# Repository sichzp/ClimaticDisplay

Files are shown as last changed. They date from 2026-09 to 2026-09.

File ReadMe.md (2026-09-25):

# 🌡 ClimaticDisplay 2.66G

> **Климатический модуль с 4-цветным графическим экраном на электронных чернилах.**

**🇬🇧 [English (short)](#english-short)** · **🇷🇺 Русский — далее по документу**

---

## English (short)

**ClimaticDisplay 2.66G** is a self-powered wall-mounted climate monitor. An
**ESP32-C3** wakes up every 20 minutes from a **TPL5110** power timer, reads
temperature, humidity and atmospheric pressure from a **BME280**, keeps the time
and the previous readings in a **DS1307Z** RTC, redraws a 2.66" 4-color e-paper
screen and cuts its own power. It runs for months on two LiFePO4 cells.

Two firmwares share the same hardware: `ESP32-C3/` is a standalone Arduino build
with NTP time sync, while `ForESPHome/` is an ESPHome + Home Assistant build that
reports data to HA and refreshes the screen only when someone is at home.
Schematics, photos and full documentation are below, in Russian.

> **Note:** the device UI and all code comments are in **Russian**. Cyrillic glyphs
> are baked into the fonts (`ESP32-C3/fonts/*.h`, `ForESPHome/fonts/FreeSansBold.ttf`
> and the `glyphs:` lists in `ForESPHome/RoomClimatic.yaml`), so an English UI would
> require regenerating them. Translations are welcome.

---

## Описание прибора

Автономный настенный прибор на базе **ESP32-C3**: измеряет температуру, влажность и атмосферное давление, раз в 20 минут просыпается по таймеру, рисует свежие данные на e-paper дисплее и снова отключает питание. Работает от пары LiFePO4 аккумуляторов.

Существует в двух вариантах с одинаковым железом, но разным ПО:

| Вариант | Прошивка | Где стоит | Обмен данными |
|---|---|---|---|
| **Рабочий** | Arduino (`ESP32-C3/`) | На работе | Автономный, без сервера |
| **Домашний** | ESPHome (`ForESPHome/`) | Дома | Интеграция с Home Assistant |

---

## 🧭 Навигация по проекту

| Документ | Описание |
|---|---|
| [📄 Описание прибора](DOC/DeviceDescription.md) | Железо, характеристики, конструкция, распиновка |
| [⚙️ Алгоритм работы](DOC/Algorithm.md) | Пошаговый алгоритм обеих прошивок (Arduino и ESPHome) с блок-схемами |

---

## 📷 Фотографии

**Экран**

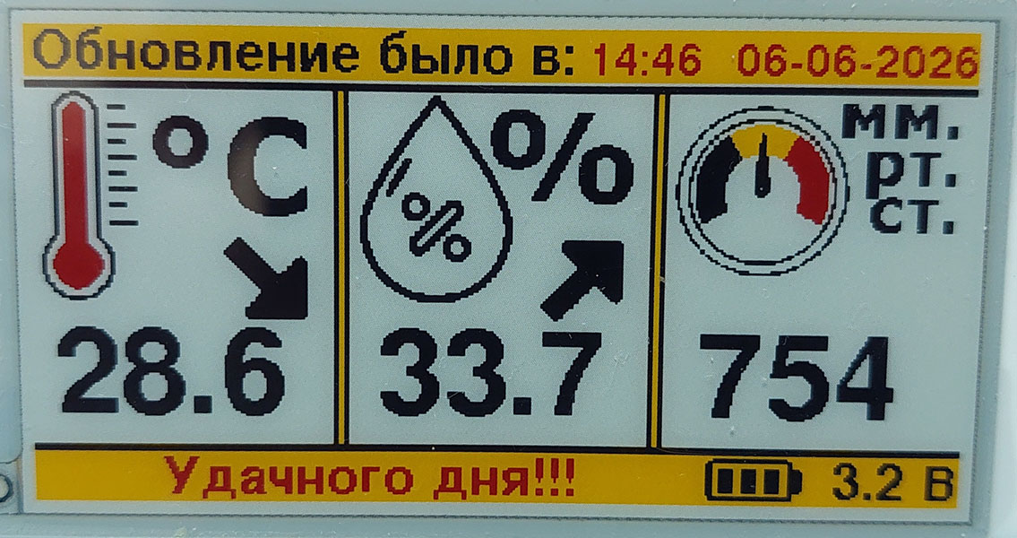
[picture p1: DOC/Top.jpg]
Дизайн экрана


**Вид сбоку**

| Справа | Слева |
|---|---|
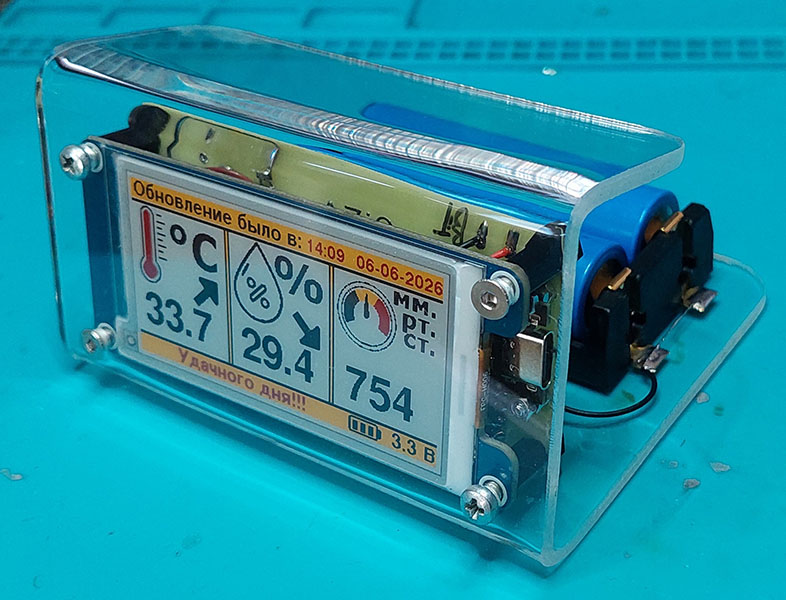
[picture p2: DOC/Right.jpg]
Вид справа
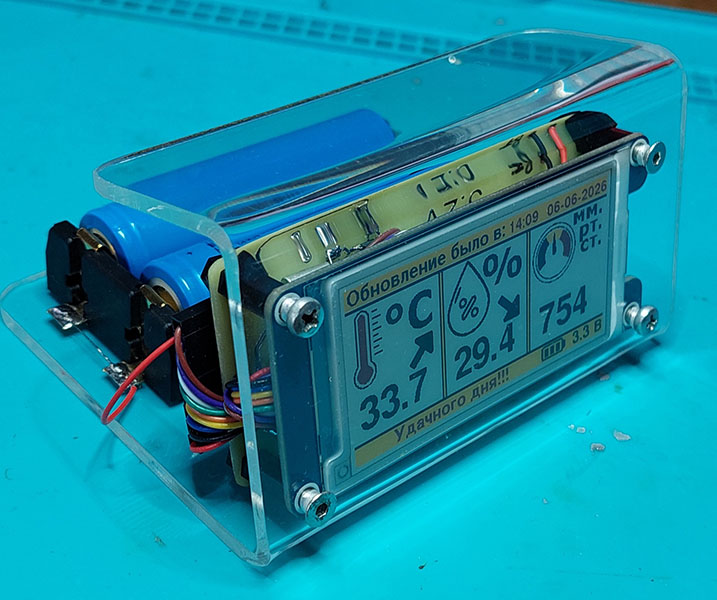
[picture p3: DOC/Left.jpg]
Вид слева
|  |  |

**Вид сзади**

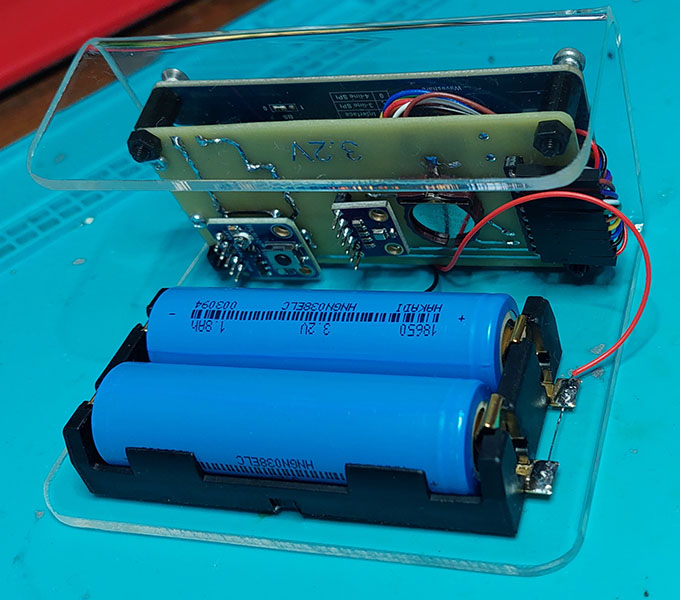
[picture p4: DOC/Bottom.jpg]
Вид сзади


**Корпус**

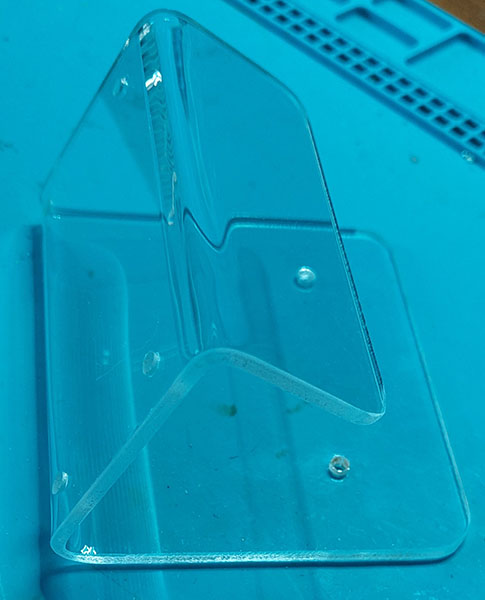
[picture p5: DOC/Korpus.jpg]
Корпус


**Схема и плата**

| Схема | Разведённая плата |
|---|---|
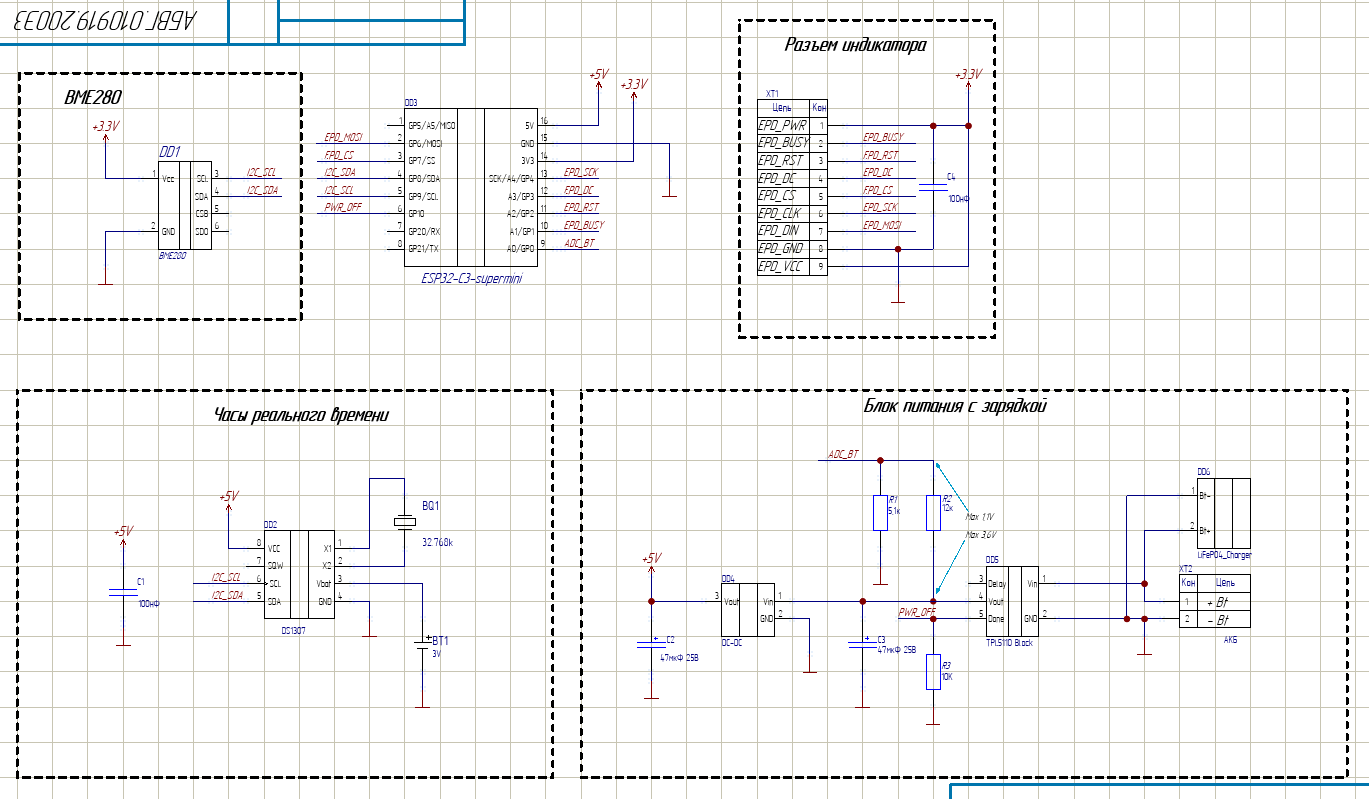
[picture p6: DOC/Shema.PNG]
Схема
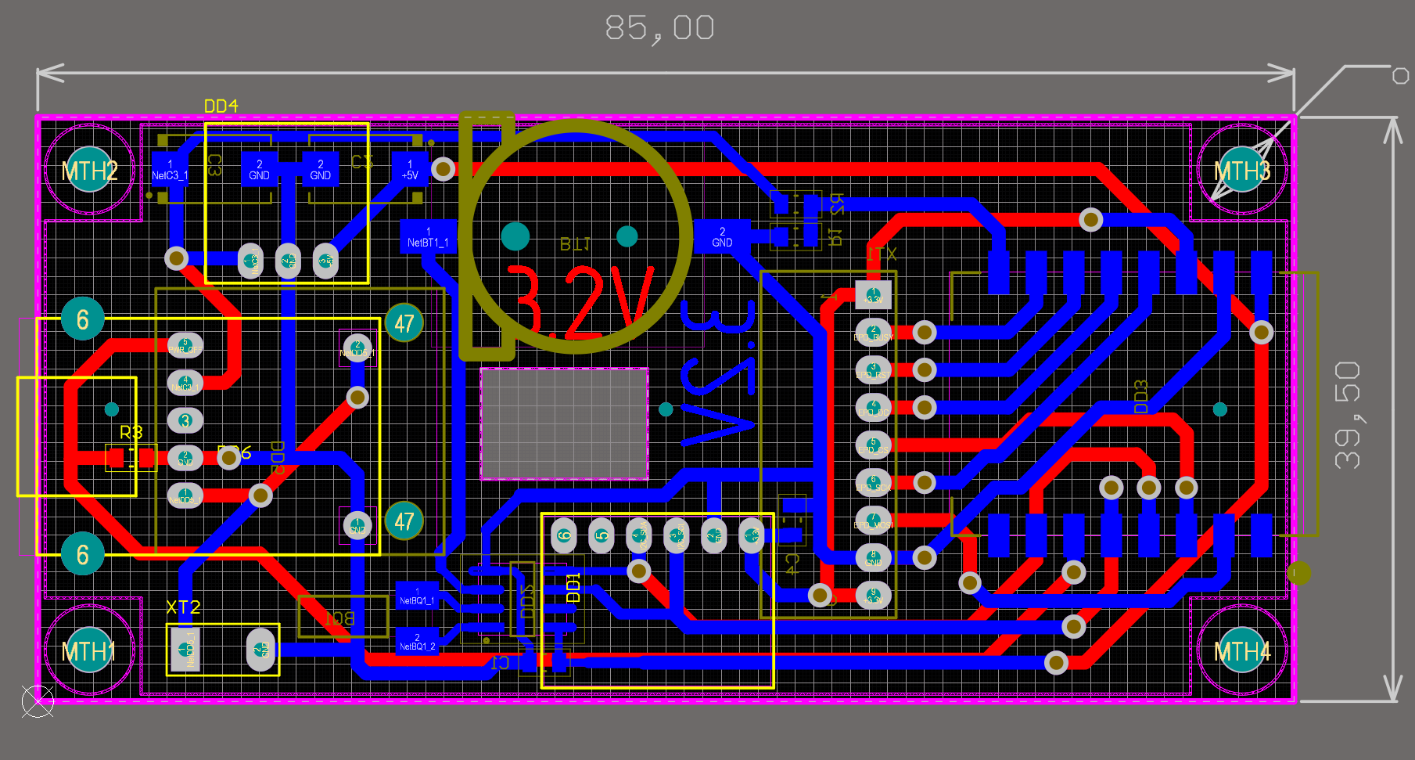
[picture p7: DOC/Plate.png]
Плата
|  |  |

| 3D модель, вид сверху | 3D модель, вид снизу |
|---|---|
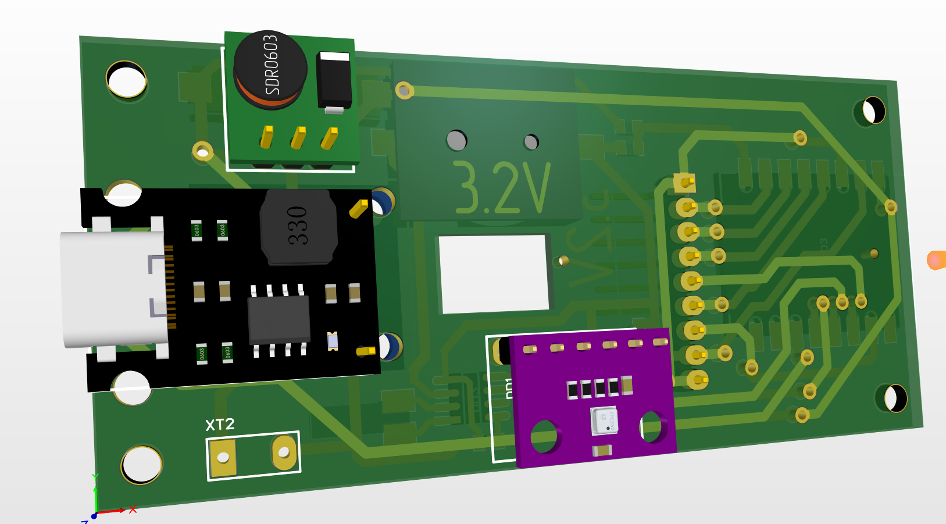
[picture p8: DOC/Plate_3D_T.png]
3D Модель платы Top
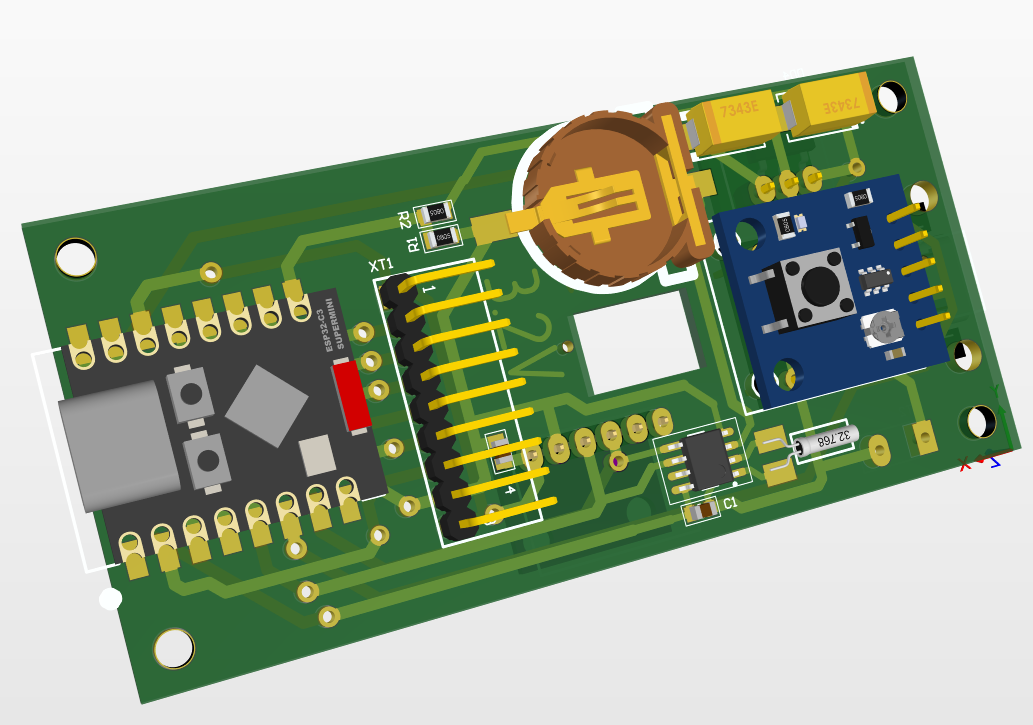
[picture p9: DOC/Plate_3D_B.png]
3D Модель платы Bottom
|  |  |

---

## 🖥 Что выводится на дисплей

1. 🌡 **Температура** + значок изменения (↑ / ↓);
2. 💧 **Влажность** + значок изменения;
3. 🌀 **Атмосферное давление** + значок изменения;
4. 🕒 **Время последнего обновления** (дата, время);
5. ⚠ **Ошибки** (если есть): соединение с сервером, общение с датчиками и часами;
6. 🔋 **Значок и напряжение заряда АКБ**.

---

## 🧰 Железо

| № | Компонент | Назначение |
|---|---|---|
| 1 | **ESP32-C3 Super Mini** | Микроконтроллерный модуль |
| 2 | **2.66" e-Paper Module (G), Waveshare** | 4-цветный графический дисплей 360×184 px |
| 3 | **BME280** | Датчик температуры, влажности и атмосферного давления |
| 4 | **DS1307Z** | Часы реального времени (кварц + батарейка) |
| 5 | **TPL5110** | Таймер включения прибора (каждые 20 минут) |
| 6 | **LiFePO4 ×2** | Аккумуляторы по 1,3 А·ч |
| 7 | **Модуль зарядки** | Зарядное устройство для АКБ |

---

## 💾 Прошивки

### 🧑‍💻 Arduino (рабочая версия) — `ESP32-C3/`

Полностью автономная прошивка: время синхронизируется по NTP через WiFi (по будням в 10:00), данные для стрелок ↑/↓ и биты ошибок хранятся в RAM DS1307Z. Ночью (23:00–04:00) прибор сразу выключается, экономя заряд АКБ.

### 🏠 ESPHome (домашняя версия) — `ForESPHome/`

Прошивка компилируется на сервере Home Assistant (файл `RoomClimatic.yaml`). Отличия от Arduino-версии:

- измеренные данные (температура, влажность, давление, напряжение АКБ, уровень WiFi) передаются в Home Assistant **при каждом включении, даже ночью**;
- время берётся с сервера Home Assistant, а при недоступности сервера — из DS1307Z; синхронизация DS1307Z — в обе стороны;
- экран не обновляется ночью (23:00–04:00) и когда **дома никого нет** (`input_boolean.people_at_home`) — экономия АКБ;
- режим **«обновление прошивки»** (`input_boolean.esphome_stay_awake`): прибор не выключается, пока флаг взведён (для OTA), максимум 1 час;
- стрелки ↑/↓ работают так же, как в Arduino-версии: прошлые показания хранятся в RAM DS1307Z;
- драйвер 4-цветного дисплея — внешний компонент `ForESPHome/components/gdey0266f51h` (портирован из GxEPD2), иконки конвертируются из Arduino-версии скриптом `ForESPHome/tools/convert_icons.py`.

> Для загрузки на сервер в папку `ForESPHome/` нужно положить файл шрифта `fonts/FreeSansBold.ttf` (GNU FreeFont — тот же шрифт, что используется в Arduino-версии), а также `secrets.yaml` с ключами `wifi_ssid` и `wifi_password` (на сервере они уже есть).

---

## 🔌 Порты модуля ESP32-C3 Super Mini

| Интерфейс | Назначение | Пин |
|---|---|---|
| **SPI** (дисплей) | SCK | D4 |
| | MOSI | D6 |
| | CS | D7 |
| | RST | D2 |
| | DC | D3 |
| | BUSY | D1 |
| | PWR | жёстко подтянут к VCC |
| **I2C** (BME280 + DS1307) | SDA | D8 |
| | SCL | D9 |
| **АЦП** (заряд АКБ) | A0 | D0 |
| **Питание** | PWR_OFF (TPL5110) | D10 |

---

## ⚙️ Алгоритм работы Arduino-версии (кратко)

Модуль **TPL5110** каждые 20 минут подаёт питание на схему. ESP32-C3 включается и выполняет:

1. Читает время и RAM из **DS1307Z**;
2. При необходимости синхронизирует время по **NTP** через WiFi (домашняя версия — ночью, рабочая — в 10:00 по будням, либо после прошлого сбоя);
3. Ночью (23:00–04:00) сразу выключается — экономия АКБ;
4. Настраивает и считывает данные из **BME280**;
5. Измеряет канал АЦП и пересчитывает его в напряжение **АКБ**;
6. Записывает данные в RAM **DS1307Z** — для показа ↑/↓ при следующем включении;
7. Формирует изображение и выводит его на **e-paper** дисплей;
8. Подаёт сигнал **TPL5110** на выключение питания.

Подробности и блок-схемы обеих версий (Arduino и ESPHome): [⚙️ Алгоритм работы](DOC/Algorithm.md)

---

## 🛠 ПО для разработки

| Что | Чем |
|---|---|
| Схема и плата | **Altium Designer 24.3.1** (компоненты из библиотеки автора — репозиторий `AltiumDesignerLibrary`) |
| Прошивка (Arduino) | **Arduino** для ESP32-C3, кодировка текстов **UTF-8** |
| Прошивка (ESPHome) | **ESPHome** (компилируется на сервере Home Assistant) |
| Корпус | **FreeCAD** |

> **ГОСТ шрифт:** для правильного отображения шрифта в Altium Designer необходимо установить в систему шрифт `Altium GOST Type A.ttf` из корня репозитория.

---

## 📚 Используемые библиотеки

| Библиотека | Для чего |
|---|---|
| [**GyverBME280**](https://github.com/GyverLibs/GyverBME280) | Датчик BME280 (Arduino-версия) |
| **DS1307** (`DS1307.h` / `DS1307.cpp`) | Собственная библиотека часов реального времени (Arduino-версия) |
| [**GxEPD2**](https://github.com/ZinggJM/GxEPD2) | Графический e-paper дисплей (Arduino-версия) |
| [**ESPHome**](https://esphome.io/) | Вся прошивка домашней версии (`ForESPHome/RoomClimatic.yaml`) |

---

## 📖 Документация

- [📄 Описание прибора](DOC/DeviceDescription.md)
- [⚙️ Алгоритм работы](DOC/Algorithm.md)
- [🙏 Благодарности и лицензии](CREDITS.md)

---

## 📜 Лицензия

Код, конфигурации, CAD-модели и документация — **MIT** (см. [LICENSE](LICENSE)): можно свободно
использовать, изменять и распространять, сохранив упоминание авторства.

Исключение — производные от GPL-компонентов: драйвер дисплея
`ForESPHome/components/gdey0266f51h/` (порт **GxEPD2**) распространяется под **GPL-3.0**,
шрифты — **GNU FreeFont** (GPL-3.0+ с Font Exception). Подробности и список сторонних
проектов: [🙏 Благодарности и лицензии](CREDITS.md).

---

👨‍💻 **Разработчик: Кабанов Алексей, 2026 г.**

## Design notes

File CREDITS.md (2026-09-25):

# 🙏 Благодарности и лицензии сторонних компонентов

> **Навигация:** [← На главную](ReadMe.md)

Проект не появился бы без чужих открытых наработок. Ниже — что и откуда взято,
чтобы было понятно, кому и за что спасибо.

---

## Сторонние проекты

| Проект | Автор | Лицензия | Где используется |
|---|---|---|---|
| [**GxEPD2**](https://github.com/ZinggJM/GxEPD2) | Jean-Marc Zingg (ZinggJM) | GPL-3.0 | Arduino-версия: вывод картинки на e-paper. Драйвер `gdey0266f51h` для ESPHome — **порт** класса `GxEPD2_266c_GDEY0266F51H` (последовательности инициализации и работа с 4-цветными панелями) |
| [**GyverBME280**](https://github.com/GyverLibs/GyverBME280) | AlexGyver (GyverLibs) | MIT | Arduino-версия: датчик BME280 |
| [**ESPHome**](https://esphome.io/) | ESPHome / Nabu Casa | GPL-3.0 | Домашняя версия: вся прошивка и внешние компоненты |
| [**GNU FreeFont**](https://www.gnu.org/software/freefont/) (FreeSans Bold) | GNU Project | GPL-3.0+ с Font Exception | Шрифты на экране: `ESP32-C3/fonts/`, `ForESPHome/fonts/FreeSansBold.ttf`. Растровые версии сделаны на [truetype2gfx](https://rop.nl/truetype2gfx/), иконки — в программе Img2Lcd |
| Демо-примеры Waveshare / Good Display для JD79667 | Waveshare / Good Display | — | Использованы как справка по регистрам панели GDEY0266F51H |
| [**Altium Designer**](https://www.altium.com/) | Altium | — | Схема и разводка платы (`Altium/`). Компоненты — из библиотеки автора (`AltiumDesignerLibrary`) |
| [**FreeCAD**](https://www.freecad.org/) | FreeCAD Community | LGPL-2.1 | 3D-модели платы и корпуса (`CAD/`) |
| [**LightBurn**](https://lightburnsoftware.com/) | LightBurn Software | — | Проект лазерной резки корпуса (`CAD/PlateLaser.lbrn2`) |

Даташиты на компоненты лежат в `DOC/`: [DS1307Z](DOC/ds1307.pdf), [TPL5110](DOC/tpl5110.pdf).

---

## Лицензия этого проекта

Всё, что написано автором (прошивка `ESP32-C3/`, конфигурация и компоненты
`ForESPHome/`, скрипты, CAD-модели, документация), распространяется по
лицензии **MIT** — см. [LICENSE](LICENSE). Коротко: можно использовать,
менять, продавать и встраивать куда угодно, главное — сохранить упоминание
авторства и не предъявлять претензий, если что-то сломалось.

**Исключение** — производные от GPL-компонентов:

- `ForESPHome/components/gdey0266f51h/` — производная работа от GxEPD2
  (GPL-3.0), поэтому распространяется под **GPL-3.0**
  (текст: <https://www.gnu.org/licenses/gpl-3.0.txt>). Если вы используете или
  распространяете этот компонент, действуют условия GPL-3.0;
- шрифты `ESP32-C3/fonts/*.h` и `ForESPHome/fonts/FreeSansBold.ttf` — GNU FreeFont
  под GPL-3.0+ с Font Exception: встраивание шрифта в изображение или документ
  не делает их производной работой, но при распространении самого файла шрифта
  действует GPL.

Отдельно: Arduino-версия прошивки собирается с библиотекой GxEPD2 (GPL-3.0),
поэтому **собранный бинарник** — уже под GPL-3.0, даже несмотря на MIT у
исходного скетча. Для домашнего хобби-проекта это никак не мешает.

---

## Навигация

[← На главную](ReadMe.md)

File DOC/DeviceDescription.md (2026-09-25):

# 📄 ClimaticDisplay 2.66G — описание прибора

> **Навигация:** [← На главную](../ReadMe.md) · [⚙️ Алгоритм работы](Algorithm.md)

---

## Назначение

Автономный настенный климатический модуль для отображения температуры, влажности и атмосферного давления. Прибор не работает постоянно: таймер **TPL5110** раз в 20 минут подаёт питание, **ESP32-C3** проводит измерение, обновляет картинку на экране и отключает питание. Благодаря e-paper дисплею картинка остаётся видимой без потребления энергии.

---

## Технические характеристики

| Параметр | Значение |
|---|---|
| Микроконтроллер | ESP32-C3 (RISC-V, WiFi) |
| Дисплей | 2.66" e-paper, 4 цвета: чёрный, белый, красный, жёлтый; 360×184 px |
| Датчик | BME280: температура, влажность, атмосферное давление |
| Часы | DS1307Z (I2C) с кварцем и резервной батарейкой |
| Питание | 2 × LiFePO4 1,3 А·ч (≈3,2 В) + модуль зарядки |
| Управление питанием | TPL5110 — включение каждые 20 минут; ночью (23:00–04:00) и при отсутствии людей дома экран не обновляется — экономия АКБ |
| Потребление | только в момент измерения и отрисовки (секунды) |

---

## Структурная схема

```mermaid
flowchart TD
    BME[BME280 датчик] -->|I2C| ESP[ESP32-C3]
    RTC[DS1307Z часы] -->|I2C| ESP
    AKB[АКБ LiFePO4] -->|делитель, АЦП A0| ESP
    TPL[TPL5110 таймер] -->|подаёт питание| ESP
    ESP -->|SPI| EPD[E-paper 2.66"]
    ESP -->|DONE, D10| TPL
```

---

## Описание узлов

### ESP32-C3 Super Mini
Микроконтроллерный модуль на базе ESP32-C3. Выполняет весь алгоритм: опрос датчиков, синхронизацию времени по NTP, отрисовку экрана и управление питанием.

### Дисплей 2.66" e-Paper (G), Waveshare
Четырёхцветный графический дисплей на электронных чернилах (GDEY0266F51H), 184×360 px (в проекте повёрнут на 90° — 360×184). Подключение по SPI. Картинка сохраняется без питания, поэтому используется полная перерисовка один раз за цикл. Работает через библиотеку **GxEPD2**.

### BME280
Датчик температуры, влажности и атмосферного давления. Подключён по I2C, работает в принудительном режиме (FORCED): по одному измерению за включение — так экономится энергия.

### DS1307Z
Микросхема часов реального времени (I2C) с кварцем и резервной батарейкой — время не сбрасывается при отключении основного питания. Помимо часов, имеет **56 байт RAM**: в них хранятся показания прошлого измерения и биты ошибок, чтобы при следующем включении нарисовать стрелки ↑/↓ и сохранить историю сбоев. Этот механизм используют обе прошивки (формат `AllData_t` совместим: переход между Arduino и ESPHome не ломает стрелки ↑/↓).

### TPL5110
Микромощный таймер, управляющий питанием всей схемы: каждые 20 минут замыкает питание. ESP32-C3 по окончании работы подаёт сигнал **DONE** (пин D10) — TPL5110 снимает питание до следующего цикла.

**Пример схемы включения TPL5110:**

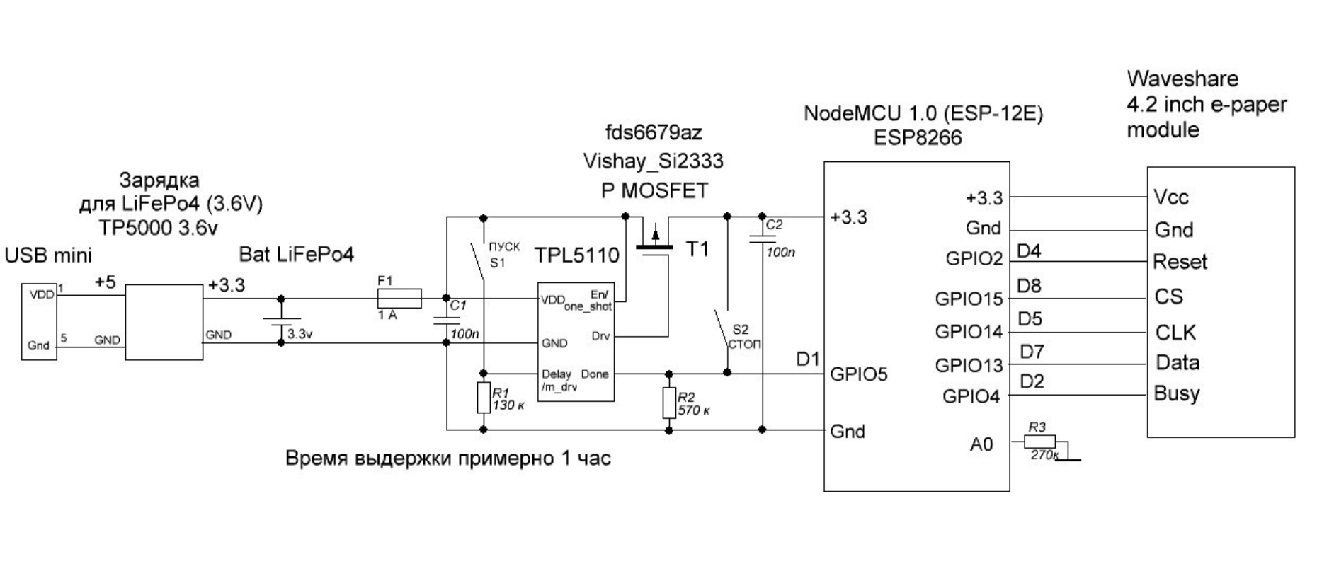
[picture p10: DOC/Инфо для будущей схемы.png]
Пример схемы включения TPL5110


Экономия АКБ реализована по-разному в двух прошивках:

- **Arduino-версия**: ночью (23:00–04:00) после чтения времени и синхронизации (при необходимости) прибор подаёт DONE сразу — измерения и обновление экрана пропускаются;
- **ESPHome-версия**: данные всегда измеряются и передаются на сервер, но экран не обновляется ночью (23:00–04:00) и когда дома никого нет (`input_boolean.people_at_home = off`); в режиме обновления прошивки (`input_boolean.esphome_stay_awake = on`) DONE не подаётся до снятия флага (максимум 1 час) — это позволяет выполнить OTA.

### Питание
Два аккумулятора **LiFePO4** по 1,3 А·ч (номинал ≈3,2 В) и модуль зарядного устройства. Уровень заряда контролируется через АЦП (пин A0). При разряде АКБ на экран выводится соответствующая ошибка.

---

## Распиновка ESP32-C3 Super Mini

| Интерфейс | Назначение | Пин |
|---|---|---|
| **SPI** (дисплей) | SCK | D4 |
| | MOSI | D6 |
| | CS | D7 |
| | RST | D2 |
| | DC | D3 |
| | BUSY | D1 |
| | PWR | жёстко подтянут к VCC |
| **I2C** (BME280 + DS1307) | SDA | D8 |
| | SCL | D9 |
| **АЦП** (заряд АКБ) | A0 | D0 |
| **Питание** | PWR_OFF (TPL5110) | D10 |

---

## Компоновка экрана

Экран 360×184 px состоит из трёх окон и двух колонтитулов:

| Зона | Координаты (x, y, ширина, высота) | Содержимое |
|---|---|---|
| Верхний колонтитул | (0, 0, 360, 20) — жёлтый | «Обновление было в: ЧЧ:ММ ДД-ММ-ГГГГ» |
| Разделитель | (0, 21, 360, 3) — чёрный | — |
| Окно температуры | иконка (1, 25, 112, 80) · стрелка (74, 80, 32, 32) · значение (8, 148) | градусник, ↑/↓, значение °C |
| Разделитель 1 | (116, 24, 2, 137) чёрный · (118, 24, 3, 137) жёлтый · (120, 24, 2, 137) чёрный | — |
| Окно влажности | иконка (123, 25, 112, 80) · стрелка (196, 80, 32, 32) · значение (132, 148) | капля, ↑/↓, значение % |
| Разделитель 2 | (238, 24, 2, 137) чёрный · (240, 24, 3, 137) жёлтый · (242, 24, 2, 137) чёрный | — |
| Окно давления | иконка (245, 25, 112, 80) · стрелка (317, 80, 32, 32) · значение (257, 148) | барометр, ↑/↓, значение мм рт. ст. |
| Нижний разделитель | (0, 161, 360, 3) — чёрный | — |
| Нижний колонтитул | (0, 164, 360, 20) — жёлтый | ошибки слева, значок АКБ (260, 165, 40, 18) и напряжение (310, 180) справа |

---

## Индикация ошибок

Ошибки хранятся в виде битовой маски (2 байта) в RAM DS1307Z и выводятся в нижнем колонтитуле экрана:

| Бит | Обозначение | На экране | Значение |
|---|---|---|---|
| 0 | DS1307Z | `\|TM\|` | МС часов реального времени не отвечает |
| 1 | BME280 | `\|BME\|` | Датчик BME280 не отвечает |
| 2 | Battery | `\|Bt\|` | АКБ разряжен |
| 3 | WiFi | `\|WF\|` | Нет подключения к WiFi |
| 4 | NTP | `\|NTP\|` | Нет ответа от сервера времени |
| 5 | TimeRST | `\|TM_Rst\|` | Время часовой МС было сброшено |
| 6–15 | — | — | Резерв |

Если ошибок нет — в нижнем колонтитуле выводится «Удачного дня!!!».

> В ESPHome-версии ошибки не хранятся в RAM, а формируются на лету по состоянию датчиков: `|TM|` — нет времени, `|BME|` — датчик не отвечает, `|Bt|` — АКБ < 2,5 В, `|WF|` — нет связи с сервером, `|OTA|` — режим ожидания прошивки. Подробнее: [⚙️ Алгоритм работы](Algorithm.md).

---

## Конструкция

- **Корпус** — модель в FreeCAD (`CAD/Корпус.FCStd`), печать/фрезеровка;
- **Плата** — разработана в Altium Designer (`Altium/`), смотри фото ниже.

| Фото | Описание |
|---|---|
| Схема | Принципиальная схема |
| Плата | Разведённая плата |
| 3D Top | 3D-модель платы, вид сверху |
| 3D Bottom | 3D-модель платы, вид снизу |
| Экран | Экран устройства |
| Корпус | Корпус |

---

## Навигация

[← На главную](../ReadMe.md) · [⚙️ Алгоритм работы](Algorithm.md)

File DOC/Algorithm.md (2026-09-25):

# ⚙️ ClimaticDisplay 2.66G — алгоритм работы

> **Навигация:** [← На главную](../ReadMe.md) · [📄 Описание прибора](DeviceDescription.md)

Документ описывает обе прошивки прибора:

- [Часть 1. Arduino-версия (рабочий прибор)](#часть-1-arduino-версия-рабочий-прибор)
- [Часть 2. ESPHome-версия (домашний прибор)](#часть-2-esphome-версия-домашний-прибор)

---

# Часть 1. Arduino-версия (рабочий прибор)

## Общая идея

Прибор не работает постоянно. Таймер **TPL5110** раз в 20 минут подаёт питание на схему, **ESP32-C3** просыпается, делает замер, обновляет экран и сам себя выключает. Поэтому весь код программы размещён в `setup()`, а `loop()` пуст.

Ночью (с 23:00 до 04:00) прибор экономит заряд АКБ: он синхронизирует время по NTP (если это нужно) и сразу выключается — без измерений и обновления экрана.

```mermaid
flowchart TD
    A[TPL5110 подаёт питание] --> B[Инициализация ESP32-C3]
    B --> C[Чтение времени из DS1307Z]
    C --> D[Чтение RAM DS1307Z]
    D --> E{Нужно обновить<br/>время по NTP?}
    E -- Да --> F[Подключение к WiFi]
    F --> G[Синхронизация по NTP]
    G --> H[Запись времени в DS1307Z]
    E -- Нет --> I{Ночь 23:00-04:00<br/>и часы в порядке?}
    H --> I
    I -- Да --> X[Сразу выключаемся<br/>без измерений]
    I -- Нет --> J[Чтение BME280]
    J --> K[Измерение АКБ]
    K --> L[Сохранение данных в RAM DS1307Z]
    L --> M[Отрисовка e-paper]
    M --> N[PWR_OFF — выключение питания]
```

---

## Пошаговый алгоритм

### Шаг 1. Чтение времени из DS1307Z

1. Проверка наличия МС на линии I2C (чтение регистра дня недели);
   - нет ответа → бит ошибки `DS1307Z`;
2. Чтение даты и времени (8 регистров, BCD);
3. Проверка актуальности: если год < 26 — часы были сброшены → бит `TimeRST`.

### Шаг 2. Чтение RAM DS1307Z

Читаются 8 байт RAM — прошлые показания (`AllDataOld`) для стрелок ↑/↓ и биты ошибок прошлого цикла.

### Шаг 3. Синхронизация времени по NTP

Условия обновления времени:

| Версия прошивки | Условие |
|---|---|
| Домашняя (`VER_FOR_HOME`) | 00:00–00:20 |
| Рабочая (по умолчанию) | 10:00–10:20 в будние дни |
| Любая | время было сброшено (`TimeRST`), или в прошлый раз не удалось подключиться к WiFi/NTP |

Порядок действий:

1. Подключение к WiFi (таймаут ~30 с) → при неудаче бит `WiFi`;
2. Запрос времени у NTP-сервера (таймаут ~30 с) → при неудаче бит `NTP`;
3. Перевод времени в BCD и запись в DS1307Z;
4. Отключение WiFi и переход модуля в `WIFI_OFF` — экономия энергии.

### Шаг 4. Ночной режим экономии АКБ

После синхронизации проверяется текущее время:

- если МС ответила, время актуально и сейчас **23:00–04:00** — прибор **сразу выключается**: измерения и обновление экрана пропускаются;
- если время было сброшено (`TimeRST`) или МС не ответила — не спим, а работаем дальше (покажем ошибку или данные).

Интервал настраивается макросами `NIGHT_START_HOUR` / `NIGHT_END_HOUR` (формат BCD).

### Шаг 5. Чтение датчика BME280

1. Датчик переводится в принудительный режим (`FORCED_MODE`) — одно измерение за включение, экономия энергии;
2. Если датчик не ответил — выставляется бит ошибки `BME280`;
3. Считываются температура и влажность (×10), давление пересчитывается в мм рт. ст. (×10).

### Шаг 6. Измерение напряжения АКБ

1. Читается канал АЦП (пин A0) через `analogReadMilliVolts()` — точнее, чем `analogRead()`;
2. Значение пересчитывается в напряжение АКБ (с учётом делителя);
3. Если напряжение ниже порога — бит ошибки `Battery`.

### Шаг 7. Сохранение данных в RAM DS1307Z

Текущие показания датчиков (8 байт структуры `AllData_t`) записываются в RAM микросхемы часов. При следующем включении они станут «старыми» и позволят нарисовать стрелки ↑/↓ изменения.

### Шаг 8. Отрисовка экрана

1. Инициализация GxEPD2, поворот на 90° (`setRotation(1)`), заливка белым;
2. Верхний колонтитул: жёлтая плашка со временем последнего обновления;
3. Три окна: температура (с градусником, окрашенным по диапазону), влажность, давление (иконка по диапазону);
4. Стрелки ↑/↓ — сравнение с прошлыми показаниями из RAM;
5. Нижний колонтитул: ошибки (или «Удачного дня!!!») + значок и напряжение АКБ;
6. `display()` — вывод картинки, `hibernate()` — перевод экрана в режим сна.

### Шаг 9. Выключение питания

Пин `PWR_OFF` (D10) переводится в высокий уровень — сигнал **DONE** для TPL5110, который снимает питание со всей схемы до следующего цикла.

---

## Отладочные макросы прошивки

| Макрос | Назначение |
|---|---|
| `DEBUG` | Вывод отладочной информации в Serial (115200) |
| `NO_BME280` | Отключить работу с BME280 |
| `NO_DS1307` | Отключить работу с DS1307 |
| `NO_GxEPD2` | Отключить работу с экраном |
| `VER_FOR_HOME` | Домашняя версия: обновление времени ночью |
| `POWER_AKB_32V` | Питание от LiFePO4 3,2 В (включено по умолчанию) |
| `POWER_AKB_42V` | Питание от LiPo 4,2 В |
| `NIGHT_START_HOUR` | Начало ночного режима: 23:00 (в формате BCD) |
| `NIGHT_END_HOUR` | Конец ночного режима: 04:00 (в формате BCD) |

---

# Часть 2. ESPHome-версия (домашний прибор)

> Конфигурация: `ForESPHome/RoomClimatic.yaml` (компилируется на сервере Home Assistant).

## Общая идея

Принцип тот же: TPL5110 включает прибор каждые 20 минут, ESP32-C3 загружается, выполняет сценарий `Execute_and_off` (запускается автоматически после загрузки) и подаёт сигнал DONE на выключение. Отличия от Arduino-версии:

- прибор всегда подключается к WiFi и Home Assistant, чтобы **передать данные датчиков** — в том числе ночью и когда дома никого нет;
- время приходит с сервера Home Assistant; при недоступности сервера используется время из DS1307Z (автономный режим);
- экран обновляется не каждое включение: ночью (23:00–04:00) и при отсутствии людей дома (`input_boolean.people_at_home = off`) отрисовка пропускается ради экономии АКБ;
- режим обновления прошивки (`input_boolean.esphome_stay_awake = on`) удерживает прибор включённым до OTA-обновления, но не более 1 часа.

```mermaid
flowchart TD
    A[TPL5110 подаёт питание] --> B[Загрузка ESPHome + подключение к WiFi]
    B --> C{Время валидно<br/>и сервер доступен?}
    C -- Нет --> W[Ожидание до 30 с]
    W --> C
    C --> D{Время валидно?}
    D -- Да --> E[ds1307.write_time<br/>сервер → DS1307Z]
    D -- Нет --> F[ds1307.read_time<br/>DS1307Z → прибор]
    E --> G[Измерение BME280, АЦП АКБ, WiFi]
    F --> G
    G --> H[Пауза 3 с — данные уходят на сервер]
    H --> I[Чтение старых данных из RAM DS1307Z]
    I --> J{Ночь 23:00-04:00<br/>или никого нет дома?}
    J -- Нет --> K[Отрисовка e-paper]
    J -- Да --> L[Экран пропускаем]
    K --> M[Сохранение данных в RAM DS1307Z]
    L --> M
    M --> N{esphome_stay_awake?}
    N -- Да --> O[Ждём снятия флага<br/>до 1 часа]
    O --> P[DONE — выключение питания]
    N -- Нет --> P
```

## Пошаговый алгоритм сценария `Execute_and_off`

### Шаг 1. Ожидание сервера и времени

После загрузки ждём 10 секунд (подключение к WiFi), затем сценарий проверяет условие «время валидно и сервер доступен» и ждёт его до 30 секунд:

- если сервер доступен — время синхронизируется с Home Assistant (платформа `homeassistant`, интервал 10 с — чтобы успеть за короткое включение);
- если сервер недоступен — продолжаем без него (автономный режим).

### Шаг 2. Синхронизация часов DS1307Z

- время валидно (есть сервер) → действие `ds1307.write_time` записывает время сервера в МС — часы остаются точными для будущих автономных включений;
- время невалидно (нет сервера) → действие `ds1307.read_time` берёт время из МС — прибор работает без сети.

### Шаг 3. Измерение датчиков

Действиями `component.update` принудительно измеряются BME280 (температура, влажность, давление → мм рт. ст.), напряжение АКБ (АЦП) и уровень WiFi. После 3-секундной паузы значения гарантированно переданы на сервер — **даже ночью и когда никого нет дома**.

### Шаг 4. Чтение старых данных из RAM DS1307Z

Из RAM DS1307Z (адреса 0x08–0x0F) читаются прошлые показания в том же формате, что и в Arduino-версии (`AllData_t`), — для стрелок ↑/↓. Если значения не проходят проверку на адекватность, стрелки не рисуются.

### Шаг 5. Решение об обновлении экрана

Экран обновляется, только если одновременно:

- сейчас **не ночь** (23:00–04:00, проверяется по часам с проверкой года — защита от мусорного времени МС);
- **кто-то есть дома** (`input_boolean.people_at_home = on`; флагу доверяем только при доступном сервере — иначе прибор не отличит «никого нет» от «нет связи»);

иначе отрисовка пропускается — экономия АКБ.

### Шаг 6. Отрисовка экрана

Картинка та же, что в Arduino-версии: колонтитулы, три окна с иконками по диапазону значений, стрелки ↑/↓, строка ошибок и значок АКБ. Отличия:

- драйвер дисплея — внешний компонент `gdey0266f51h` (порт GxEPD2): то же разрешение, те же 4 цвета;
- шрифты — **FreeSans Bold** (`fonts/FreeSansBold.ttf`, GNU FreeFont) в тех же размерах, что в Arduino-версии: 48px (24pt), 20px (10pt) и 16px (8pt) — картинка выглядит так же;
- иконки — BMP-файлы, сконвертированные из `ESP32-C3/img` скриптом `ForESPHome/tools/convert_icons.py`;
- при взведённом `esphome_stay_awake` в строке ошибок выводится `|OTA|`.

### Шаг 7. Сохранение данных в RAM DS1307Z

Текущие показания записываются в RAM МС (если BME280 исправен) — в следующем включении они станут «старыми» для стрелок ↑/↓. Запись выполняется независимо от того, обновлялся ли экран.

### Шаг 8. Выключение питания

- `esphome_stay_awake = off` → переключатель `Done_Out` подаёт высокий уровень на GPIO10 (DONE для TPL5110) — питание снимается;
- `esphome_stay_awake = on` → сценарий ждёт снятия флага (до 1 часа — защита), затем выключает питание. Пока флаг взведён, можно выполнить OTA-обновление.

## Индикация ошибок (ESPHome-версия)

Битовых флагов в RAM нет — строка ошибок формируется на лету по состоянию датчиков:

| Код | Значение |
|---|---|
| `\|TM\|` | время не синхронизировано (нет сервера и МС) |
| `\|BME\|` | BME280 не отвечает |
| `\|Bt\|` | напряжение АКБ < 2,5 В |
| `\|WF\|` | нет соединения с сервером Home Assistant |
| `\|OTA\|` | взведён режим ожидания прошивки |

Если ошибок нет — «Удачного дня!!!».

## Соответствие режимов и объектов Home Assistant

| Объект | Назначение |
|---|---|
| `input_boolean.people_at_home` | «Дома кто-то есть»: off — экран не обновляется |
| `input_boolean.esphome_stay_awake` | «Обновление прошивки»: on — прибор не выключается (OTA) |
| Датчики `roomclimatic.*` | Температура, влажность, давление (гПа и мм рт. ст.), напряжение АКБ, уровень WiFi |

---

## Навигация

[← На главную](../ReadMe.md) · [📄 Описание прибора](DeviceDescription.md)

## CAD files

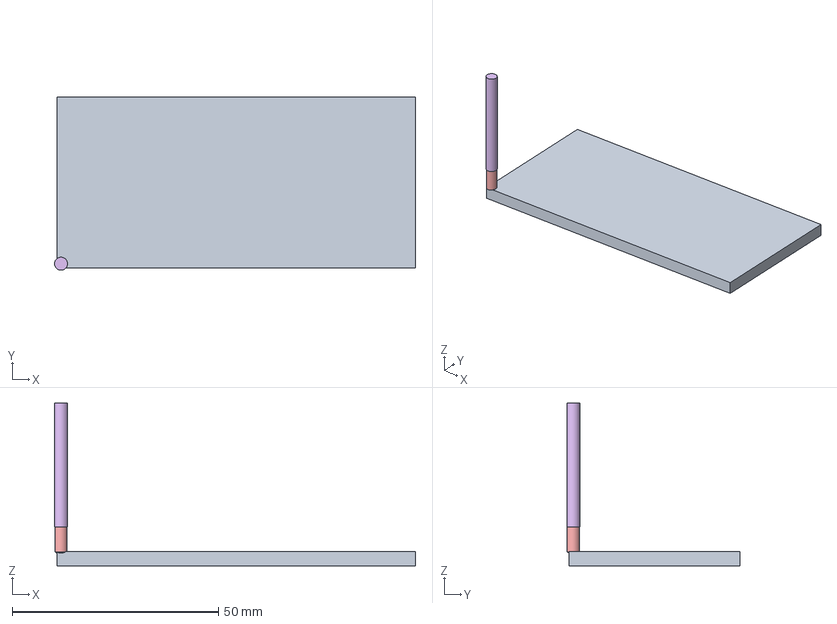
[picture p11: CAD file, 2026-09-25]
CAD/Плата.FCStd
87.6 x 42.1 x 39.5 mm
Drill
Drill001
Drill002
Drill003
Drill004
Endmill
Model-Тело
Model-Тело001
Model-Тело002
Model-Тело003
Model-Тело004
Model-Тело005
Stock002
Stock001
Stock003
Stock004
Stock005
Stock006

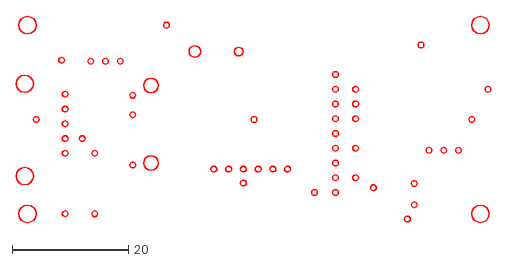
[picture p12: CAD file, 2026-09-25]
CAD/DRL.dxf
81.8 x 35.5

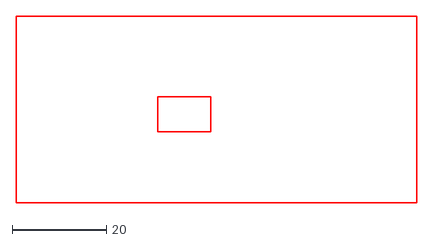
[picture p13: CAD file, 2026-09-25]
CAD/Plate.dxf
85.0 x 39.5

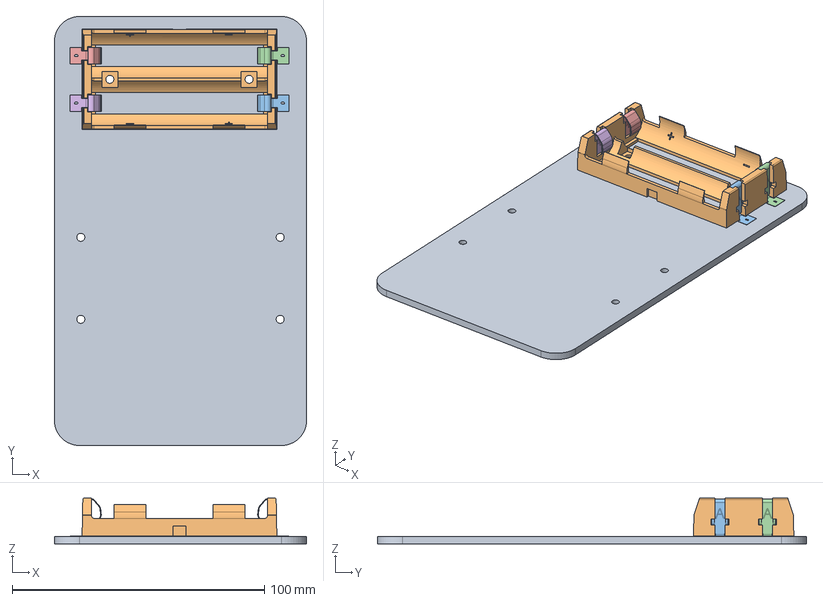
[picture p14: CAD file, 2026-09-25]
CAD/Корпус.FCStd
100.0 x 170.0 x 18.1 mm
Тело
BLM Blossom Electronics STM THM FOR 18650 Battery Holder V1.2
BLM Blossom Electronics STM THM FOR 18650 Battery Holder V1.001
BLM Blossom Electronics STM THM FOR 18650 Battery Holder V1.002
BLM Blossom Electronics STM THM FOR 18650 Battery Holder V1.003
BLM Blossom Electronics STM THM FOR 18650 Battery Holder V1.004

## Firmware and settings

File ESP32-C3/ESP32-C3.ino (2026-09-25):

/*
 * =============================================================================
 * ClimaticDisplay 2.66G — рабочая (автономная) версия прошивки
 * =============================================================================
 * Плата: ESP32-C3 Super Mini.
 *
 * Логика: таймер TPL5110 раз в 20 минут подаёт питание; ESP32-C3 просыпается,
 * читает время и RAM из DS1307Z, при необходимости синхронизирует часы по NTP,
 * измеряет BME280 и напряжение АКБ, рисует картинку на 4-цветном e-paper
 * дисплее и снова выключает питание (сигнал DONE на пине PWR_OFF).
 * Поэтому весь алгоритм размещён в setup(), а loop() пуст.
 *
 * Домашний вариант (ESPHome + Home Assistant) — в папке ../ForESPHome.
 * Описание прибора — ../DOC/DeviceDescription.md, алгоритм — ../DOC/Algorithm.md.
 *
 * ВАЖНО: перед компиляцией обязательно установить библиотеки GxEPD2 и
 * GyverBME280 из набора библиотек Arduino (Менеджер библиотек).
 * =============================================================================
 */



#include <WiFi.h>
#include "time.h"
#include <esp_sntp.h>
#include <GyverBME280.h>
#include "DS1307.h"
#include "Var.h"

// Подключить графическую библиотеку
#include <GxEPD2_4C.h>
//#include <Fonts/FreeMonoBold9pt7b.h>
#define GxEPD2_DRIVER_CLASS GxEPD2_266c_GDEY0266F51H // GDEY0266F51H 184x360
#define MAX_HEIGHT(EPD) (EPD::HEIGHT <= (32768) / (EPD::WIDTH / 8) ? EPD::HEIGHT : (32768) / (EPD::WIDTH / 8))
GxEPD2_4C<GxEPD2_DRIVER_CLASS, MAX_HEIGHT(GxEPD2_DRIVER_CLASS)> display(GxEPD2_DRIVER_CLASS(/*CS*/ 7, /*DC=*/ 3, /*RST=*/ 2, /*BUSY=*/ 1)); // Good Display ESP32E6-E01 board
#undef MAX_HEIGHT


// Шрифты
#include "fonts/FreeSansBold8.h"
#include "fonts/FreeSansBold10.h"
#include "fonts/FreeSansBold24pt7b.h"

// Картинки

// Стрелки вверх и вниз
#include "img/Up.h"
#include "img/Down.h"

// Значки термометра
#include "img/TermometrGen.h"
#include "img/TermometrNormRED.h"
#include "img/TermometrMinRED.h"
#include "img/TermometrMaxRED.h"

// Значки влажности
#include "img/HumidityBW.h"
#include "img/HumidityRY.h"

// Значки атм. давления
#include "img/PressureMinBW.h"
#include "img/PressureNormBW.h"
#include "img/PressureMaxBW.h"
#include "img/PressureMinMaxY.h"
#include "img/PressureNormY.h"
#include "img/PressureMinNormR.h"
#include "img/PressureMaxR.h"

// Значки батарейки
#include "img/BatteryGenBW.h"
#include "img/BatteryGenY.h"
#include "img/BatteryMaxBW.h"
#include "img/BatteryHalfR.h"
#include "img/BatteryMinR.h"


#define VER_FOR_HOME		// Версия для работы из дома. Обновление Времени ночью
//Иначе -  Версия для работы. Обновление времени днем по будням 
// Ну и разные точки Вай-Фай

// Вид питания
//#define POWER_AKB_42V		// Питание от АКБ LiPO 4,2В и слежением за разрядом
#define POWER_AKB_32V		// Питание от АКБ LiFePO 3,2В и слежением за разрядом
// Питание от сети 5В - ничего включать не надо


#define PWR_PIN		10			// Нога вылючения питания подтяжка в ноль. 1 - выкл питания

// Ночной режим экономии АКБ: в этом интервале прибор после чтения времени сразу выключается
// без измерений и обновления экрана. Время задано в формате BCD МС DS1307.
#define NIGHT_START_HOUR	0x23	// Начало ночного режима: 23:00
#define NIGHT_END_HOUR		0x04	// Конец ночного режима:   04:00


// Для просмотра отладочной информации раскомментировать строку DEBUG ниже,
// в Ардуино включить режим "Инструменты->USB CDC on boot->Enable"
// и открыть окно монитора порта (выставить скорость 115200).
// В релизной (публикуемой) версии отладочный вывод отключён.
//#define DEBUG

// В отладочных целях можно отключить блок программы, раскоментировав нужную строку ниже
//#define NO_BME280		// Не использовать BME280
//#define NO_DS1307		// Не использовать DS1307
//#define NO_GxEPD2		// Не использовать работу с экраном


// для получения времени
#ifdef VER_FOR_HOME
const char *ssid = "XXXXXXXX";
const char *password = "XXXXXXXX";
#else
const char *ssid = "YYYYYYY";
const char *password = "YYYYYYY";
#endif

const char *ntpServer1 = "pool.ntp.org";
const char *ntpServer2 = "time.nist.gov";

const long gmtOffset_sec = (3600 * 3);		// третий часовой пояс
const int daylightOffset_sec = 0;					// переход на летнее время

struct tm timeinfo;

bool NTP_Flag = false;

AllData_t AllData;				// Данные для текущей работы и записи в RAM DS1307Z
AllData_t AllDataOld;			// Старые данные для чтения из RAM DS1307Z

C_DS_1307 *MyDateTime;

GyverBME280 bme; 						// Объект датчика BME280

float	Battery = 0;				// Уровень заряда АКБ, В


// Callback function (gets called when time adjusts via NTP)
void timeavailable(struct timeval *t)
{
#ifdef DEBUG
	Serial.println("Получил корректировку времени от NTP!");
#endif
	
	if (!getLocalTime(&timeinfo)) 
	{
#ifdef DEBUG
		Serial.println("Время от NTP не получено.");
#endif
//		return;
	}
	else
		NTP_Flag = 1;		// Флаг ожидания времени от NTP
}


void setup() {

	// Опа, включились! 

#ifdef DEBUG
	Serial.begin(115200);
	delay(1000);		// Пусть все датчики нормально проснутся.
	Serial.println("Включились!!!");
#endif

AllData.Err.Errors = 0;

	pinMode(PWR_PIN, OUTPUT);
	digitalWrite(PWR_PIN, LOW);


	delay(100);




#ifndef NO_DS1307
// --------------------------------------------------------------------------------------
// Раздел 1. Прочитать всю DS1307
// --------------------------------------------------------------------------------------

#ifdef DEBUG
	Serial.println("------------ Инициализируем DS1307 -------------");
#endif
	// Инициализируем и прочтем данные из микросхемы часов реального времени
	MyDateTime = new C_DS_1307();


	if(MyDateTime->Error == 0)
	{
#ifdef DEBUG
		Serial.println("DS1307 Ответила, все ОК.");
#endif
		MyDateTime->GetDateTime();
		if(MyDateTime->Actual)
		{
			AllData.Err.Bits.TimeRST = 0;
#ifdef DEBUG
			Serial.println("Данные актуальны");
#endif
		}			
		else
		{
			AllData.Err.Bits.TimeRST = 1; 		// Флаг сброса времени
#ifdef DEBUG
			Serial.println("Данные не актуальны");
#endif
		}

	}
	else
	{
		AllData.Err.Bits.DS1307Z = 1;	// Флаг ошибки МС часов
#ifdef DEBUG
		Serial.println("Не отвечает МС DS1307!!!");
#endif

	}

#ifdef DEBUG
	Serial.print("Сырые данные даты и времени: ");
	for(int i = 0; i < 8; i++)
	{
		Serial.print(MyDateTime->DateTime.Buff[i]);
		Serial.print(", ");
	}
	Serial.println(" ");
	
	Serial.println("Данные Времени разбитые на части BCD.");
	Serial.print("День недели: ");
	Serial.println(MyDateTime->DateTime.Week);
	Serial.print("Время: ");
	Serial.print(MyDateTime->DateTime.Hour.BCD_2);
	Serial.print(MyDateTime->DateTime.Hour.BCD_1);
	Serial.print(":");
	Serial.print(MyDateTime->DateTime.Minutes.BCD_2);
	Serial.print(MyDateTime->DateTime.Minutes.BCD_1);
	Serial.print(":");
	Serial.print(MyDateTime->DateTime.Second.BCD_2);
	Serial.println(MyDateTime->DateTime.Second.BCD_1);

	Serial.print("Дата: ");
	Serial.print(MyDateTime->DateTime.Date.BCD_2);
	Serial.print(MyDateTime->DateTime.Date.BCD_1);
	Serial.print(":");
	Serial.print(MyDateTime->DateTime.Month.BCD_2);
	Serial.print(MyDateTime->DateTime.Month.BCD_1);
	Serial.print(":");
	Serial.print(MyDateTime->DateTime.Year.BCD_2);
	Serial.println(MyDateTime->DateTime.Year.BCD_1);
#endif

	
	// Прочитаем нужные регистры RAM из микросхемы часов.
	if(!AllData.Err.Bits.DS1307Z)
	{
#ifdef DEBUG
		Serial.println("Прочтем RAM:");
#endif
		MyDateTime->GetBytes(AllDataOld.Buff, 8, 8); // sizeof(AllDataOld.Buff)
	}

#ifdef DEBUG
	// Для отладки выведем всё что считали
	if(!AllData.Err.Bits.DS1307Z)
	{
		Serial.print("Данные RAM: ");
		for(int i = 0; i < 8; i++)		//  sizeof(AllDataOld.Buff)
		{
			Serial.print(AllDataOld.Buff[i]);
			Serial.print(",");
		}
		Serial.println(" ");
	}
	
	Serial.println("Выведем тоже самое в виде нормальных данных!");
	Serial.print("Старая Температура: ");
	Serial.println(AllDataOld.Temperature);
	Serial.print("Старая Влажность: ");
	Serial.println(AllDataOld.Humidity);
	Serial.print("Старое Давление: ");
	Serial.println(AllDataOld.Pressure);
	
#endif


#ifdef DEBUG
		Serial.println("Решаем забирать ли время из инета.");
#endif

	bool Vskr = ((MyDateTime->DateTime.Week == 1) || (MyDateTime->DateTime.Week == 7))? false : true;	// Если выходной, то не обновляемся
#ifdef DEBUG
		Serial.print("Определим будний день или выходной - ");
		if(Vskr)
			Serial.println("Будний!");
		else
			Serial.println("Выходной!");
#endif



	// Если сейчас больше полночи, но меньше 20 мин первого или в прошлый раз не смог получить время из сети
#ifdef VER_FOR_HOME		// Для домашней версии примерно в полночь
	if(((MyDateTime->DateTime.Hour.Dat == 0x00) && (MyDateTime->DateTime.Minutes.Dat <= 0x20)) || (AllData.Err.Bits.TimeRST == 1) || AllDataOld.Err.Bits.WiFi || AllDataOld.Err.Bits.NTP)
#else					// Для работы - в десять дня (день недели нафиг, потому что все равно питания нет в выходные.)
	if(((MyDateTime->DateTime.Hour.Dat == 0x10) && (MyDateTime->DateTime.Minutes.Dat <= 0x20) && (Vskr)) || (AllData.Err.Bits.TimeRST == 1) || AllDataOld.Err.Bits.WiFi || AllDataOld.Err.Bits.NTP)
#endif
//	if(1)
	{
		// Тут соединимся с Вай-Фай и далее с сервером NTP и получим точное время, которое и запишем в МС DS1307
		// Этот код содран из примера
#ifdef DEBUG
		Serial.println("Надо обновить время...  ");
		Serial.printf("Connecting to %s ", ssid);
#endif
		WiFi.begin(ssid, password);

		uint8_t Timer = 60; // 30 сек

		while (WiFi.status() != WL_CONNECTED)
		{
			delay(500);
			Timer--;
			if(Timer == 0)						// Чтоб не зависнуть навсегда
			{
				AllData.Err.Bits.WiFi = 1;		// Запишем ошибку соединения
				break;
			}

#ifdef DEBUG
			Serial.print(".");
#endif
		}

#ifdef DEBUG
		if(AllData.Err.Bits.WiFi == 0)
			Serial.println(" Соединились!");
		else
			Serial.println(" Не соединились!");
#endif

		if(AllData.Err.Bits.WiFi == 0)	// Если есть подключение к инету
		{
			// установим call-back функцию
			sntp_set_time_sync_notification_cb(timeavailable);

			configTime(gmtOffset_sec, 0, ntpServer1, ntpServer2);		// Запуск синхронизации

			uint8_t Timer = 30; // 30 сек

			while(!NTP_Flag)
			{
				delay(1000);	// ждем 
				Timer--;
				if(Timer == 0)
				{
					AllData.Err.Bits.NTP = 1;		// Запишем ошибку получения времени от сервера
#ifdef DEBUG
					Serial.println("NTP не ответил");
#endif
					continue;
				}
			}

			if(NTP_Flag)		// если NTP ответил
			{
#ifdef DEBUG
					Serial.println("NTP синхронизировался!");
					Serial.print("Выведем полученное время: ");
					Serial.print(timeinfo.tm_hour);
					Serial.print(":");
					Serial.print(timeinfo.tm_min);
					Serial.print(":");
					Serial.println(timeinfo.tm_sec);

					Serial.print("Выведем полученную дату: ");
					Serial.print(timeinfo.tm_mday);
					Serial.print("-");
					Serial.print((timeinfo.tm_mon + 1));
					Serial.print("-");
					Serial.println((timeinfo.tm_year - 100));
					
					Serial.print("День недели: ");
					Serial.println(timeinfo.tm_wday);
					
					
#endif
					// Переводим данные в формат BCD
					MyDateTime->DateTime.Hour.BCD_2 = timeinfo.tm_hour / 10;	// Десятки часов
					MyDateTime->DateTime.Hour.BCD_1 = timeinfo.tm_hour % 10;	// Единицы часов

					MyDateTime->DateTime.Minutes.BCD_2 = timeinfo.tm_min / 10;	// Десятки минут
					MyDateTime->DateTime.Minutes.BCD_1 = timeinfo.tm_min % 10;	// Единицы минут

					MyDateTime->DateTime.Second.BCD_2 = timeinfo.tm_sec / 10;	// Десятки секунд
					MyDateTime->DateTime.Second.BCD_1 = timeinfo.tm_sec % 10;	// Единицы секунд

					MyDateTime->DateTime.Date.BCD_2 = timeinfo.tm_mday / 10;	// Десятки дня
					MyDateTime->DateTime.Date.BCD_1 = timeinfo.tm_mday % 10;	// Единицы дня

					MyDateTime->DateTime.Month.BCD_2 = (timeinfo.tm_mon + 1) / 10;	// Десятки месяца	// Тут месяц 0..11, т.е. надо прибавить 1, чтоб было 1..12
					MyDateTime->DateTime.Month.BCD_1 = (timeinfo.tm_mon + 1) % 10;	// Единицы месяца

					MyDateTime->DateTime.Year.BCD_2 = (timeinfo.tm_year - 100) / 10;	// Десятки года		//  вот тут пишут, что надо вычесть 100.... да, так и есть
					MyDateTime->DateTime.Year.BCD_1 = (timeinfo.tm_year - 100) % 10;	// Единицы года

					MyDateTime->DateTime.Week = timeinfo.tm_wday + 1;								// День недели 0..6, 0 - воскресенье
			
		
			}
			
			//Отключаемся от сети
			WiFi.disconnect(true);
			WiFi.mode(WIFI_OFF);

#ifdef DEBUG
			Serial.println("Запишем полученные данные в микросхему.");
#endif
			// Сохраним время в МС
			if(!AllData.Err.Bits.DS1307Z)
				MyDateTime->SetDateTime();

#ifdef DEBUG
			Serial.println("Для проверки записи, прочтем данные и выведем их");
			
			MyDateTime->GetDateTime();

			Serial.print("Сырые данные даты и времени: ");
			for(int i = 0; i < 8; i++)
			{
				Serial.print(MyDateTime->DateTime.Buff[i]);
				Serial.print(", ");
			}
			Serial.print("  \r\n");
			
			Serial.println("Данные Времени разбитые на части BCD.");
			Serial.print("День недели: ");
			Serial.println(MyDateTime->DateTime.Week);
			Serial.print("Время: ");
			Serial.print(MyDateTime->DateTime.Hour.BCD_2);
			Serial.print(MyDateTime->DateTime.Hour.BCD_1);
			Serial.print(":");
			Serial.print(MyDateTime->DateTime.Minutes.BCD_2);
			Serial.print(MyDateTime->DateTime.Minutes.BCD_1);
			Serial.print(":");
			Serial.print(MyDateTime->DateTime.Second.BCD_2);
			Serial.println(MyDateTime->DateTime.Second.BCD_1);

			Serial.print("Дата: ");
			Serial.print(MyDateTime->DateTime.Date.BCD_2);
			Serial.print(MyDateTime->DateTime.Date.BCD_1);
			Serial.print(":");
			Serial.print(MyDateTime->DateTime.Month.BCD_2);
			Serial.print(MyDateTime->DateTime.Month.BCD_1);
			Serial.print(":");
			Serial.print(MyDateTime->DateTime.Year.BCD_2);
			Serial.println(MyDateTime->DateTime.Year.BCD_1);
#endif
		}
	}
#ifdef DEBUG
	else
		Serial.println("Решили не забирать время из инета.");
#endif

	// Ночной режим экономии АКБ: с 23:00 до 04:00 измерения и обновление экрана пропускаем -
	// сразу выключаемся. Синхронизация времени с NTP (если была нужна) уже выполнена выше,
	// так что время ночью всё равно забирается из инета.
	// Если МС не ответила (Error) или время было сброшено (TimeRST) - не спим, а работаем дальше.
	if((MyDateTime->Error == 0) && (AllData.Err.Bits.TimeRST == 0) &&
		((MyDateTime->DateTime.Hour.Dat >= NIGHT_START_HOUR) || (MyDateTime->DateTime.Hour.Dat < NIGHT_END_HOUR)))
	{
#ifdef DEBUG
		Serial.println("Сейчас ночь. Экономим заряд АКБ - выключаемся без измерений.");
#endif
		digitalWrite(PWR_PIN, HIGH);	// Сигнал TPL5110 на выключение питания
		return;
	}

	
#endif


#ifndef NO_BME280
// --------------------------------------------------------------------------------------
// Раздел 2. Прочитать и обработать данные датчика BME280 
// --------------------------------------------------------------------------------------

#ifdef DEBUG
		Serial.println("-------- Инициализация датчика BME280 ---------- ");
#endif

	bme.setMode(FORCED_MODE);		// Принудительный режим
	
	if(!bme.begin())		// Если датчик не инициализирован
	{
#ifdef DEBUG
		Serial.println("Датчик BME280 не найден;");
#endif
		AllData.Err.Bits.BME280 = 1;	// Флаг ошибки термодатчика
	}
#ifdef DEBUG
	else
		Serial.println("Датчик BME280 найден и проиницализирован;");
#endif


	if(AllData.Err.Bits.BME280 == 0)		// Если датчик инициализирован
	{
		// Считаем все данные с микросхемы BME280
		bme.oneMeasurement();			//Запуск преобразования
#ifdef DEBUG
		Serial.println("Запустили преобразование...");
#endif
		while (bme.isMeasuring());		// Ждем окончания преобразования
#ifdef DEBUG
		Serial.println("Данные готовы.");
#endif
		
		AllData.Temperature = (uint16_t)(bme.readTemperature() * 10.0);
		AllData.Humidity = (uint16_t)(bme.readHumidity() * 10.0);
		AllData.Pressure = (uint16_t)pressureToMmHg(bme.readPressure());
		
#ifdef DEBUG
		Serial.println("Полученные данные:");
		Serial.print("Температура:");
		Serial.println(((float)AllData.Temperature / 10.0));
		Serial.print("Влажность:");
		Serial.println(((float)AllData.Humidity / 10.0));
		Serial.print("Атм.давление:");
		Serial.println(AllData.Pressure);
#endif

	}
#endif


// --------------------------------------------------------------------------------------
// Раздел 3. Измерить уровень заряда АКБ 
// --------------------------------------------------------------------------------------

#ifdef POWER_AKB_32V		// Для АКБ 3,2В

#ifdef DEBUG
	Serial.print("--------- Прочтем АЦП ----------\r\n");
#endif

	Battery = (float)analogReadMilliVolts(0) / 1000.0 * 3.3; 

#ifdef DEBUG
	Serial.print("АЦП = ");
	Serial.print(Battery);
	Serial.print(" Вольт \r\n");
#endif

	if(Battery < 0.9)
		AllData.Err.Bits.Battery = 1; 		// Батарея разряжена!
#endif

#ifdef POWER_AKB_42V		// Для АКБ 4,2В

#ifdef DEBUG
	Serial.print("--------- Прочтем АЦП ----------\r\n");
#endif

	Battery = analogReadMilliVolts(0) / 1000;

#ifdef DEBUG
	Serial.print("АЦП = ");
	Serial.print(Battery);
	Serial.print(" Вольт \r\n");
#endif

	if(Battery < 0.9)
		AllData.Err.Bits.Battery = 1; 		// Батарея разряжена!
#endif


#ifndef NO_DS1307
// --------------------------------------------------------------------------------------
// Раздел 4. Записать в микросхему часов полученные сейчас данные для следующего включения
// --------------------------------------------------------------------------------------
#ifdef DEBUG
	Serial.println("----- Запись массива в МС DS1307Z. -----------");
#endif
	if(!AllData.Err.Bits.DS1307Z)
		MyDateTime->SetBytes(AllData.Buff, 8, 8); // Записываем в память текущие данные
#endif


#ifndef NO_GxEPD2
// --------------------------------------------------------------------------------------
// Раздел 5. Сформируем картинку экрана и выведем ее на экран
// --------------------------------------------------------------------------------------


char buffer[20];	// Строка для преобразования в нее чисел


#ifdef DEBUG
	Serial.println("Инициализация графической библиотеки.");
	display.init(115200);	
#else
	display.init(0); 
#endif

	display.setRotation(1);
	display.fillScreen(GxEPD_WHITE);
	

#ifdef DEBUG
	Serial.println("Сформируем избражение в памяти.");
#endif
	
#ifdef DEBUG
	Serial.println("Верхний колонтитул.");
#endif
	// Верхний колонтитул
	display.fillRect(0, 0,  360, 20, GxEPD_YELLOW);
	display.fillRect(0, 21, 360, 3, GxEPD_BLACK);

#ifndef NO_DS1307
	display.setFont(&FreeSansBold10pt8b);
	display.setTextColor(GxEPD_BLACK);
	display.setCursor(3, 16);
	display.print("Обновление было в: ");

	// Создадим строку времени и даты.
	buffer[0] = MyDateTime->DateTime.Hour.BCD_2 + '0';
	buffer[1] = MyDateTime->DateTime.Hour.BCD_1 + '0';
	buffer[2] = ':';
	buffer[3] = MyDateTime->DateTime.Minutes.BCD_2 + '0';
	buffer[4] = MyDateTime->DateTime.Minutes.BCD_1 + '0';
	buffer[5] = ' ';
	buffer[6] = ' ';
	buffer[7] = ' ';
	buffer[8] = MyDateTime->DateTime.Date.BCD_2 + '0';
	buffer[9] = MyDateTime->DateTime.Date.BCD_1 + '0';
	buffer[10] = '-';
	buffer[11] = MyDateTime->DateTime.Month.BCD_2 + '0';
	buffer[12] = MyDateTime->DateTime.Month.BCD_1 + '0';
	buffer[13] = '-';
	buffer[14] = '2';
	buffer[15] = '0';
	buffer[16] = MyDateTime->DateTime.Year.BCD_2 + '0';
	buffer[17] = MyDateTime->DateTime.Year.BCD_1 + '0';
	buffer[18] = 0;
	buffer[19] = 0;
	
#ifdef DEBUG
	Serial.print("Строка даты времени в верхнем колонтитуле: ");
	Serial.print(buffer);
	Serial.println(" ");
#endif


	display.setFont(&FreeSansBold8pt8b);
	display.setTextColor(GxEPD_RED);
	display.setCursor(213, 16);
	display.print(buffer);
#else
	display.setFont(&FreeSansBold10pt8b);
	display.setTextColor(GxEPD_RED);
	display.setCursor(50, 16);
	display.print("Сегодня чудесный день!!!");
#endif


	// Окно температуры
#ifdef DEBUG
	Serial.println("Окно температуры: ");
#endif
	// Значок градусника
	display.drawBitmap(1, 25, gImage_TermometrGen, 112, 80, GxEPD_BLACK);

	if(AllData.Temperature  < 180)
		display.drawBitmap(1, 25, gImage_TermometrMinRED, 112, 80, GxEPD_RED);		// Значок Min температуры
	else if(AllData.Temperature < 280)
		display.drawBitmap(1, 25, gImage_TermometrNormRED, 112, 80, GxEPD_RED);		// Значок Norm температуры
	else
		display.drawBitmap(1, 25, gImage_TermometrMaxRED, 112, 80, GxEPD_RED);		// Значок Max температуры
#ifndef NO_DS1307
	// Значок Повышения или понижения
	if(AllData.Temperature < AllDataOld.Temperature)
		display.drawBitmap(74, 80, gImage_Down , 32, 32, GxEPD_BLACK);			// Если понижается
	else if(AllData.Temperature > AllDataOld.Temperature)
		display.drawBitmap(74, 80, gImage_Up, 32, 32, GxEPD_BLACK);			// Если повышается
	// Если значение не изменилось, то значок не показываем
#endif
	// Значение
	display.setFont(&FreeSansBold24pt7b);
	display.setTextColor(GxEPD_BLACK);
	display.setCursor(8, 148);
	display.setTextSize(1);
	
	dtostrf((float)((float)AllData.Temperature / 10.0), 4, 1, buffer);
	display.print(buffer);
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
void loop() {

	// Пусто: прибор не работает постоянно. Весь алгоритм выполняется один раз
	// за включение в setup(), после чего питание снимается (см. комментарий вверху файла).

}

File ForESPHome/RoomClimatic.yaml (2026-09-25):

# =============================================================================
# RoomClimatic — домашняя версия ClimaticDisplay 2.66G на ESPHome
# =============================================================================
# Плата: ESP32-C3 Super Mini
# Железо: то же, что у рабочей версии (Arduino), см. ../ReadMe.md
#   - дисплей GDEY0266F51H 2.66" 4-цветный (кастомный компонент components/)
#   - BME280 (I2C 0x76) + DS1307Z (I2C 0x68)
#   - АКБ LiFePO4 3,2В, АЦП GPIO0 (делитель, коэффициент 3.3)
#   - TPL5110: будит прибор каждые 20 минут, GPIO10 = DONE (выключение)
#
# Логика работы (скрипт Execute_and_off, запускается после загрузки):
#   1. Ждём соединения с сервером Home Assistant и валидного времени.
#   2. Синхронизируем DS1307: есть связь — пишем время сервера в МС,
#      нет связи — берём время из МС (автономный режим).
#   3. Измеряем датчики и передаём данные на сервер ВСЕГДА,
#      даже ночью и когда никого нет дома.
#   4. Экран обновляем, только если: не ночь (23:00–04:00),
#      дома кто-то есть (input_boolean.people_at_home) и время валидно.
#   5. Выключаем питание сигналом TPL5110, кроме режима ожидания
#      прошивки (input_boolean.esphome_stay_awake — для OTA-обновления).
#
# Перед загрузкой на сервер в папку с этим файлом положить:
#   - папку components/ (драйвер дисплея);
#   - папку img/ (иконки, генерируются скриптом tools/convert_icons.py);
#   - папку fonts/ (FreeSansBold.ttf — тот же шрифт, что в Arduino-версии);
#   - secrets.yaml с ключами:
#       wifi_ssid, wifi_password  — доступ к домашней сети;
#       api_encryption_key        — ключ шифрования API (сгенерировать заново
#                                   или взять прежний, чтобы не перепривязывать
#                                   прибор в Home Assistant);
#       ap_password               — пароль резервной точки доступа прибора.
# В репозиторий secrets.yaml не попадает (см. .gitignore).
# =============================================================================

external_components:
  - source:
      type: local
      path: components

esphome:
  name: roomclimatic
  friendly_name: RoomClimatic
  platformio_options:
    board_build.f_flash: 40000000L
    board_build.flash_mode: dio
    board_build.flash_size: 4MB
  on_boot:
    priority: 300
    then:
      - delay: 10s
      - script.execute: Execute_and_off

esp32:
  variant: esp32c3
  flash_size: 4MB
  framework:
    type: esp-idf

logger:
  level: DEBUG

api:
  encryption:
    key: !secret api_encryption_key

ota:
  - platform: esphome

wifi:
  ssid: !secret wifi_ssid
  password: !secret wifi_password
  ap:
    ssid: RoomClimatic Fallback Hotspot
    password: !secret ap_password

captive_portal:

# ---------------------------------------------------------------------------
# Шины: I2C (BME280 + DS1307) и SPI (дисплей)
# ---------------------------------------------------------------------------
i2c:
  id: i2c_bus
  sda: GPIO8
  scl: GPIO9
  frequency: 100kHz
  scan: false

spi:
  clk_pin: GPIO4
  mosi_pin: GPIO6

# ---------------------------------------------------------------------------
# Время: основное - с сервера Home Assistant, резервное - из DS1307Z.
# Часы МС хранят местное время (UTC+3, без перехода на летнее время).
# ---------------------------------------------------------------------------
time:
  - platform: ds1307_local
    id: rtc_time
    address: 0x68
    i2c_id: i2c_bus
    timezone: "MSK-3"
    update_interval: never  # читаем вручную действием ds1307_local.read_time
  - platform: homeassistant
    id: MyDateTime
    update_interval: 10s   # чтобы успеть синхронизироваться за короткое включение
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

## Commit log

2026-09-25 Add ClimaticDisplay firmware, hardware and docs
    Autonomous wall-mounted climate module on ESP32-C3 with a 4-color
    2.66" e-paper display (GDEY0266F51H), BME280 sensor, DS1307Z RTC and
    TPL5110 power timer, powered by two LiFePO4 cells.
    Contents:
    - ESP32-C3/ Arduino firmware (autonomous version)
    - ForESPHome/ ESPHome + Home Assistant version, with custom
    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
    [ClimaticDisplay_2_66_G.PrjPcb, DRL.dxf, Plate.PcbDoc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]
2026-09-25 Update schematic, PCB and 3D render images
    Add the missing DOC/Plate.png, which is referenced by ReadMe.md and
    DOC/DeviceDescription.md, and refresh the other board images:
    - DOC/Shema.PNG - updated schematic
    - DOC/Plate.png - PCB layout view (new)
    - DOC/Plate_3D_T.png - PCB 3D render, top
    - DOC/Plate_3D_B.png - PCB 3D render, bottom
